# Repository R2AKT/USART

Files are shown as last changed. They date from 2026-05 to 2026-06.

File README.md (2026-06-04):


License addendum - https://github.com/R2AKT/USART/blob/main/Addendum.txt
# USART
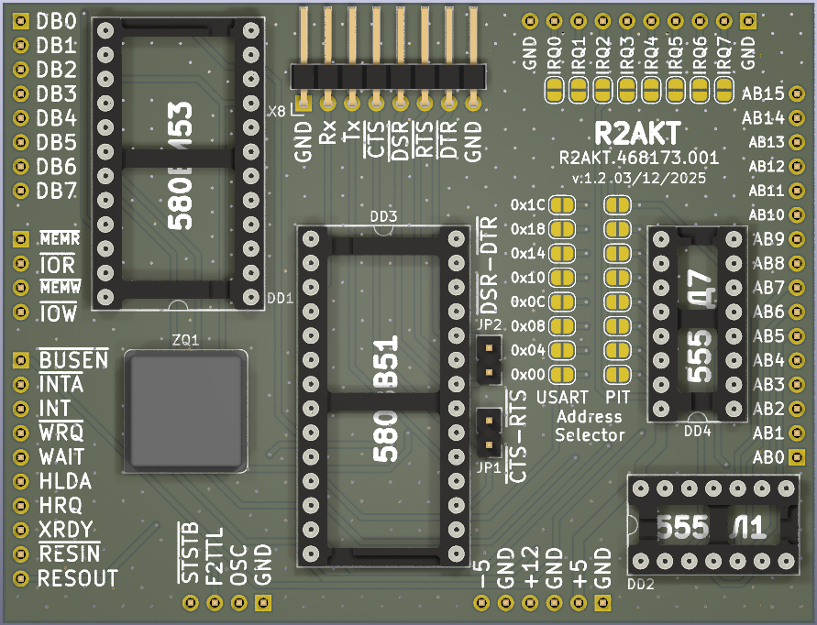
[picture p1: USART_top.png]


Serial port module (USART). For Mega-80 (Mega-580) DIY 8-bit micro-computer - https://github.com/R2AKT/Mega-80.

Based on 580VV51 (8251) and 580VI53 (8253).

Status: Tested. Prescaler x1 and x16, speed up to 38400.

Модуль последовательного порта (USART). Для самодельной 8-битной микро-ЭВМ - https://github.com/R2AKT/Mega-80.

На основе 580ВВ51 (8251) и 580ВИ53 (8253).

Статус: Протестирован. Работает в режиме x1 и x16, на скорости до 38400.

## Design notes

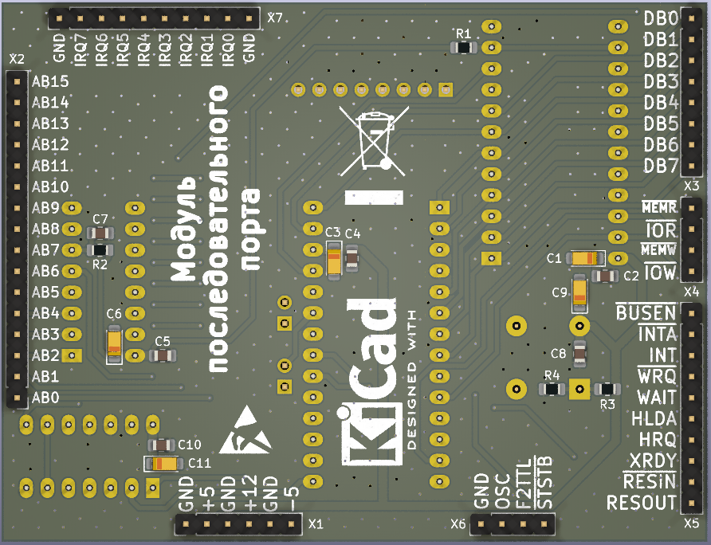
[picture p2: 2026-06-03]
USART_btn.png

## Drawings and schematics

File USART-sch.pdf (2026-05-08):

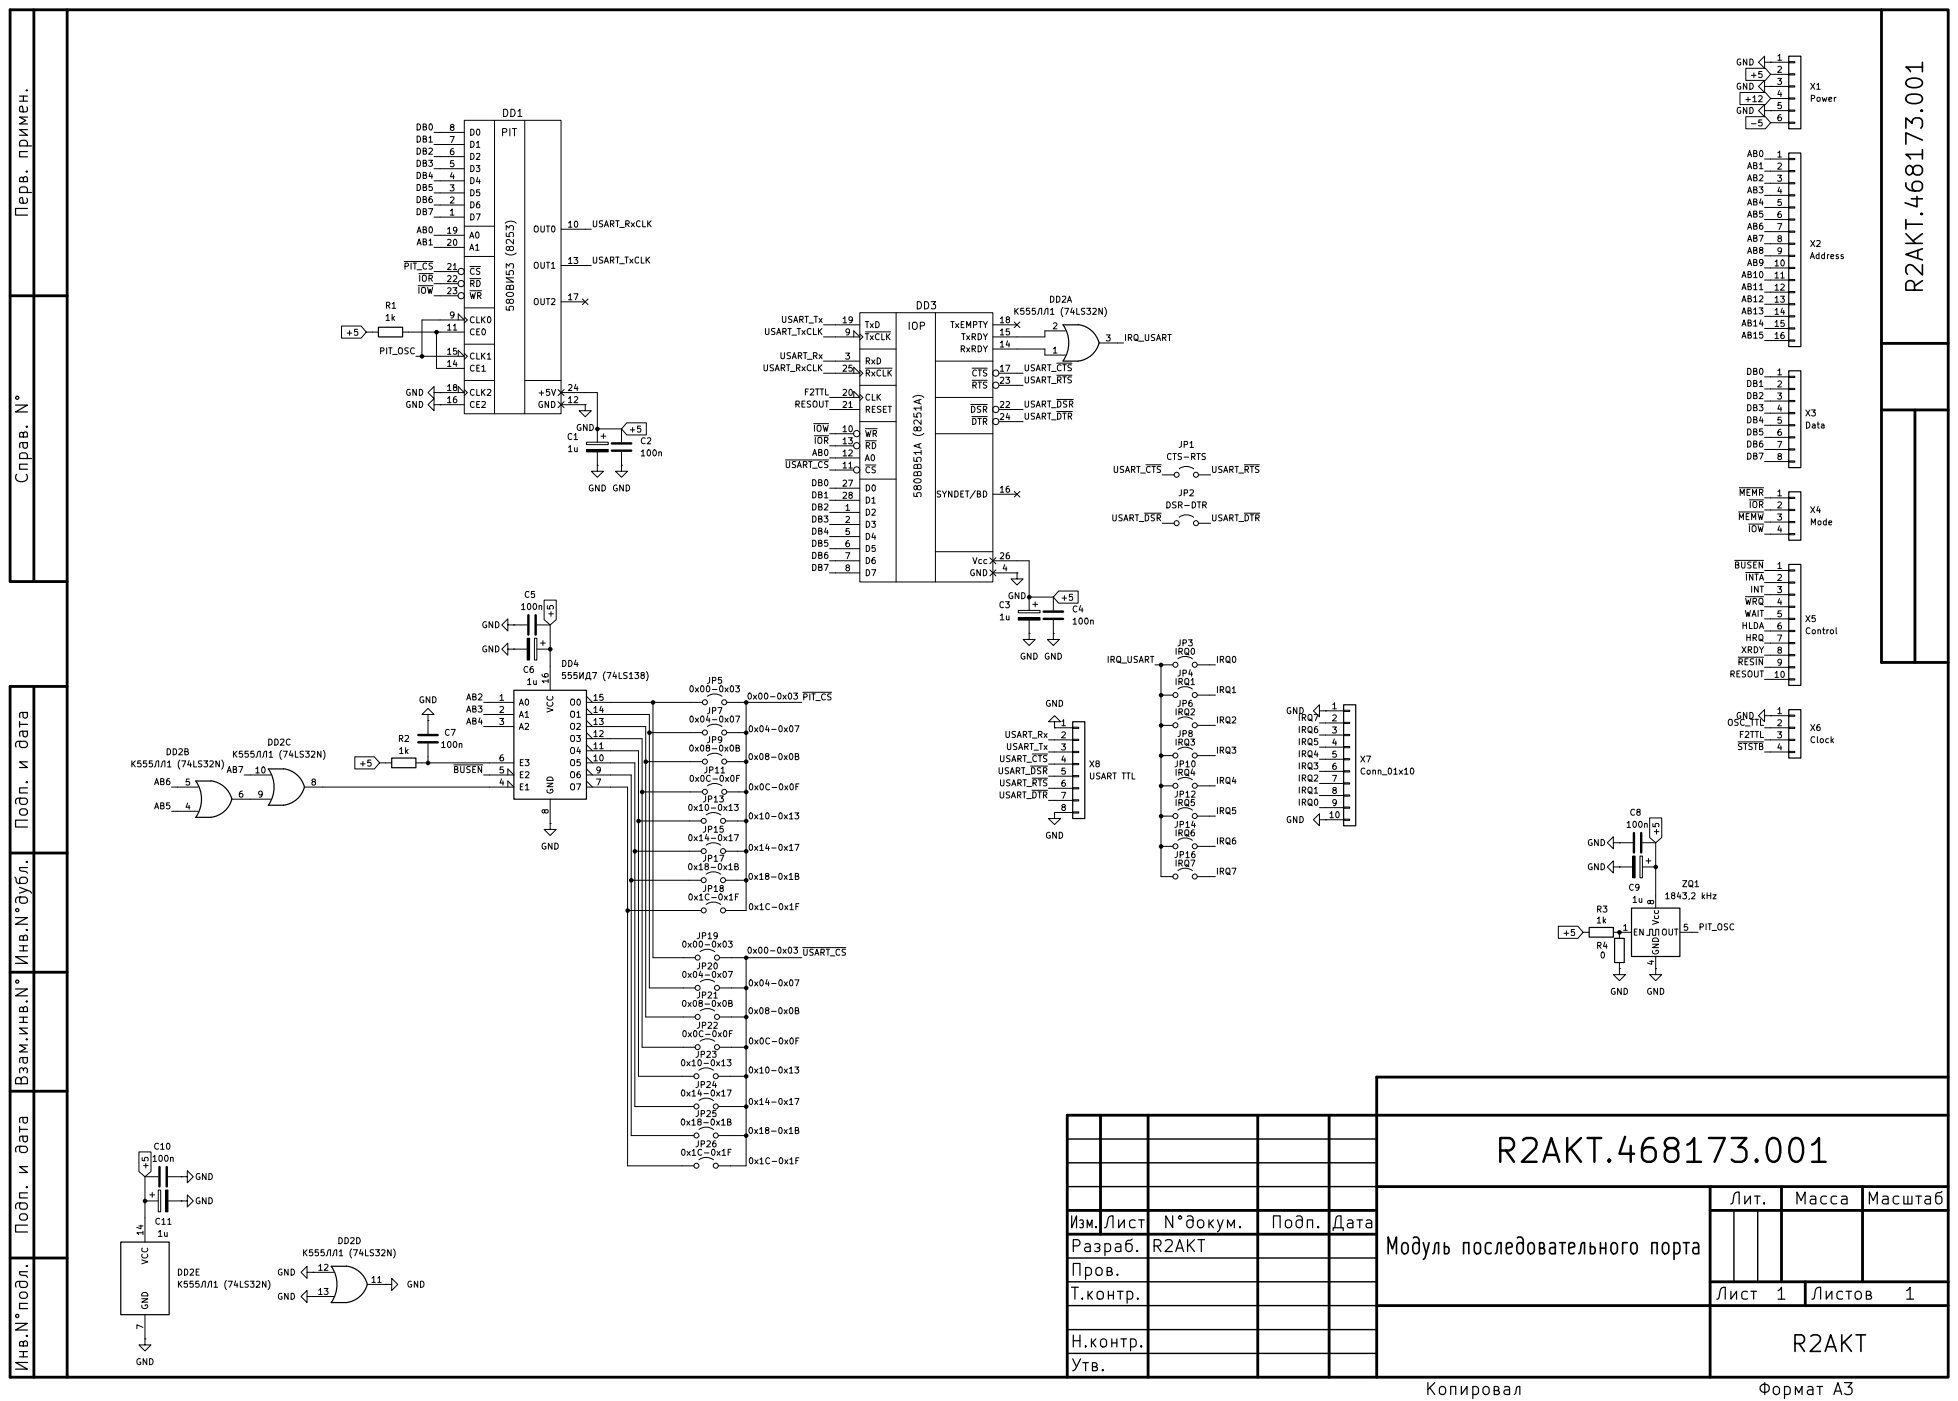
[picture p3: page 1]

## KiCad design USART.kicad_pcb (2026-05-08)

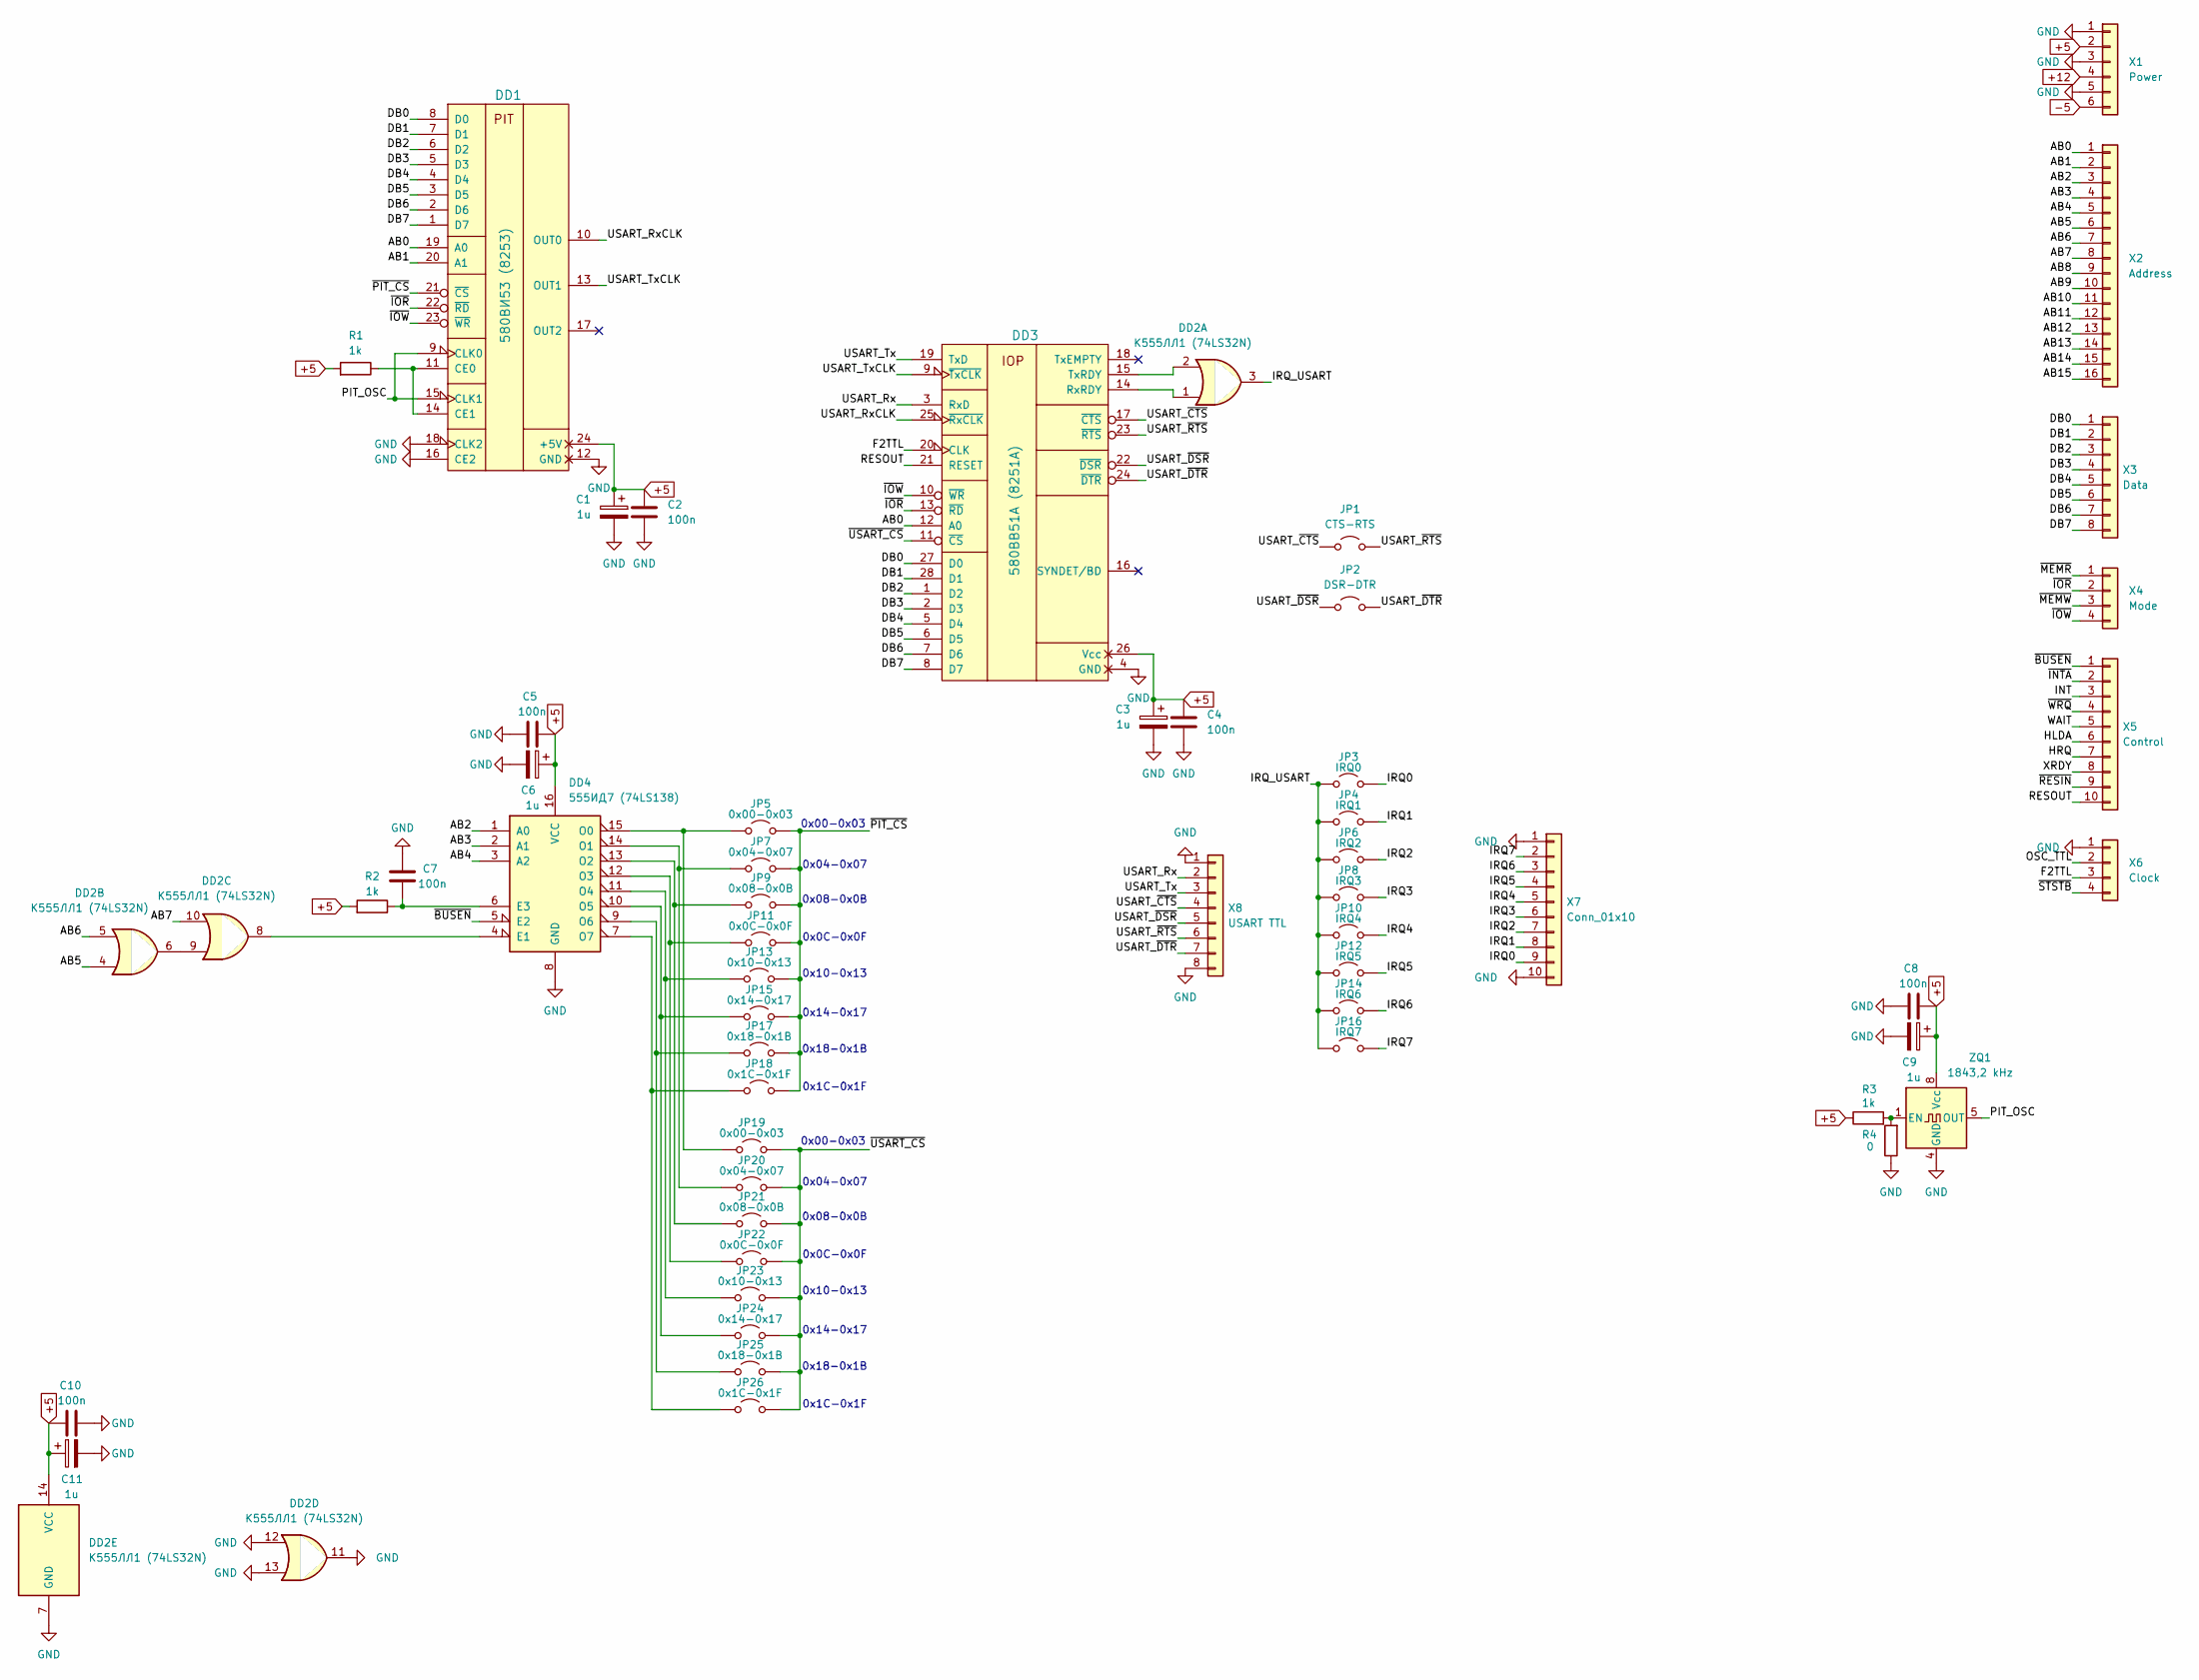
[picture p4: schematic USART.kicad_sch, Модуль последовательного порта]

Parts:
C1, C3, C6, C9, C11: 1u; CP_EIA-3216-18_Kemet-A_Pad1.58x1.35mm_HandSolder
C2, C4, C5, C7, C8, C10: 100n; C_0805_2012Metric_Pad1.18x1.45mm_HandSolder
DD1: 580ВИ53 (8253); DIP-24_W15.24mm_Socket_LongPads
DD2: К555ЛЛ1 (74LS32N); DIP-14_W7.62mm_Socket_LongPads
DD3: 580ВВ51А (8251A); DIP-28_W15.24mm_Socket_LongPads
DD4: 555ИД7 (74LS138); DIP-16_W7.62mm_Socket_LongPads
JP1: CTS-RTS; PinHeader_1x02_P2.54mm_Vertical
JP2: DSR-DTR; PinHeader_1x02_P2.54mm_Vertical
JP3: IRQ0; SolderJumper-2_P1.3mm_Open_RoundedPad1.0x1.5mm
JP4: IRQ1; SolderJumper-2_P1.3mm_Open_RoundedPad1.0x1.5mm
JP5, JP19: 0x00-0x03; SolderJumper-2_P1.3mm_Open_RoundedPad1.0x1.5mm
JP6: IRQ2; SolderJumper-2_P1.3mm_Open_RoundedPad1.0x1.5mm
JP7, JP20: 0x04-0x07; SolderJumper-2_P1.3mm_Open_RoundedPad1.0x1.5mm
JP8: IRQ3; SolderJumper-2_P1.3mm_Open_RoundedPad1.0x1.5mm
JP9, JP21: 0x08-0x0B; SolderJumper-2_P1.3mm_Open_RoundedPad1.0x1.5mm
JP10: IRQ4; SolderJumper-2_P1.3mm_Open_RoundedPad1.0x1.5mm
JP11, JP22: 0x0C-0x0F; SolderJumper-2_P1.3mm_Open_RoundedPad1.0x1.5mm
JP12: IRQ5; SolderJumper-2_P1.3mm_Open_RoundedPad1.0x1.5mm
JP13, JP23: 0x10-0x13; SolderJumper-2_P1.3mm_Open_RoundedPad1.0x1.5mm
JP14: IRQ6; SolderJumper-2_P1.3mm_Open_RoundedPad1.0x1.5mm
JP15, JP24: 0x14-0x17; SolderJumper-2_P1.3mm_Open_RoundedPad1.0x1.5mm
JP16: IRQ7; SolderJumper-2_P1.3mm_Open_RoundedPad1.0x1.5mm
JP17, JP25: 0x18-0x1B; SolderJumper-2_P1.3mm_Open_RoundedPad1.0x1.5mm
JP18, JP26: 0x1C-0x1F; SolderJumper-2_P1.3mm_Open_RoundedPad1.0x1.5mm
R1, R2, R3: 1k; R_0805_2012Metric_Pad1.20x1.40mm_HandSolder
R4: 0; R_0805_2012Metric_Pad1.20x1.40mm_HandSolder
X1: Power; PinHeader_1x06_P2.54mm_Vertical
X2: Address; PinHeader_1x16_P2.54mm_Vertical
X3: Data; PinHeader_1x08_P2.54mm_Vertical
X4: Mode; PinHeader_1x04_P2.54mm_Vertical
X5: Control; PinHeader_1x10_P2.54mm_Vertical
X6: Clock; PinHeader_1x04_P2.54mm_Vertical
X7: Conn_01x10; PinHeader_1x10_P2.54mm_Vertical
X8: USART TTL; PinHeader_1x08_P2.54mm_Horizontal
ZQ1: 1843,2 kHz; Oscillator_DIP-8_LargePads

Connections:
+5: C1.1, C2.1, C3.1, C4.1, C5.1, C6.1, C8.1, C9.1, C10.1, C11.1, DD1.24 (+5V), DD2.14 (VCC), DD3.26 (Vcc), DD4.16 (VCC), R1.2, R2.2, R3.1, X1.2, ZQ1.8 (Vcc)
+12: X1.4
-5: X1.6
/AB0: DD1.19 (A0), DD3.12 (A0), X2.1
/AB1: DD1.20 (A1), X2.2
/AB2: DD4.1 (A0), X2.3
/AB3: DD4.2 (A1), X2.4
/AB4: DD4.3 (A2), X2.5
/AB5: DD2.4, X2.6
/AB6: DD2.5, X2.7
/AB7: DD2.10, X2.8
/AB8: X2.9
/AB9: X2.10
/AB10: X2.11
/AB11: X2.12
/AB12: X2.13
/AB13: X2.14
/AB14: X2.15
/AB15: X2.16
/DB0: DD1.8 (D0), DD3.27 (D0), X3.1
/DB1: DD1.7 (D1), DD3.28 (D1), X3.2
/DB2: DD1.6 (D2), DD3.1 (D2), X3.3
/DB3: DD1.5 (D3), DD3.2 (D3), X3.4
/DB4: DD1.4 (D4), DD3.5 (D4), X3.5
/DB5: DD1.3 (D5), DD3.6 (D5), X3.6
/DB6: DD1.2 (D6), DD3.7 (D6), X3.7
/DB7: DD1.1 (D7), DD3.8 (D7), X3.8
/F2TTL: DD3.20 (CLK), X6.3
/HLDA: X5.6
/HRQ: X5.7
/INT: X5.3
/IRQ0: JP3.2 (B), X7.9
/IRQ1: JP4.2 (B), X7.8
/IRQ2: JP6.2 (B), X7.7
/IRQ3: JP8.2 (B), X7.6
/IRQ4: JP10.2 (B), X7.5
/IRQ5: JP12.2 (B), X7.4
/IRQ6: JP14.2 (B), X7.3
/IRQ7: JP16.2 (B), X7.2
/IRQ_USART: DD2.3, JP3.1 (A), JP4.1 (A), JP6.1 (A), JP8.1 (A), JP10.1 (A), JP12.1 (A), JP14.1 (A), JP16.1 (A)
/OSC_TTL: X6.2
/PIT_OSC: DD1.9 (CLK0), DD1.15 (CLK1), ZQ1.5 (OUT)
/RESOUT: DD3.21 (RESET), X5.10
/USART_Rx: DD3.3 (RxD), X8.2
/USART_RxCLK: DD1.10 (OUT0), DD3.25 (~RxCLK)
/USART_Tx: DD3.19 (TxD), X8.3
/USART_TxCLK: DD1.13 (OUT1), DD3.9 (~TxCLK)
/USART_~CTS: DD3.17 (~CTS), JP1.1 (A), X8.4
/USART_~DSR: DD3.22 (~DSR), JP2.1 (A), X8.5
/USART_~DTR: DD3.24 (~DTR), JP2.2 (B), X8.7
/USART_~RTS: DD3.23 (~RTS), JP1.2 (B), X8.6
/WAIT: X5.5
/XRDY: X5.8
/~BUSEN: DD4.5 (E2), X5.1
/~INTA: X5.2
/~IOR: DD1.22 (~RD), DD3.13 (~RD), X4.2
/~IOW: DD1.23 (~WR), DD3.10 (~WR), X4.4
/~MEMR: X4.1
/~MEMW: X4.3
/~PIT_CS: DD1.21 (~CS), JP5.2 (B), JP7.2 (B), JP9.2 (B), JP11.2 (B), JP13.2 (B), JP15.2 (B), JP17.2 (B), JP18.2 (B)
/~RESIN: X5.9
/~STSTB: X6.4
/~USART_CS: DD3.11 (~CS), JP19.2 (B), JP20.2 (B), JP21.2 (B), JP22.2 (B), JP23.2 (B), JP24.2 (B), JP25.2 (B), JP26.2 (B)
/~WRQ: X5.4
GND: C1.2, C2.2, C3.2, C4.2, C5.2, C6.2, C7.2, C8.2, C9.2, C10.2, C11.2, DD1.12 (GND), DD1.16 (CE2), DD1.18 (CLK2), DD2.7 (GND), DD2.11, DD2.12, DD2.13, DD3.4 (GND), DD4.8 (GND), R4.1, X1.1, X1.3, X1.5, X6.1, X7.1, X7.10, X8.1, X8.8, ZQ1.4 (GND)
unnamed: DD1.11 (CE0), DD1.14 (CE1), R1.1
unnamed: DD2.6, DD2.9
unnamed: DD2.1, DD3.14 (RxRDY)
unnamed: DD2.2, DD3.15 (TxRDY)
unnamed: DD2.8, DD4.4 (E1)
unnamed: C7.1, DD4.6 (E3), R2.1
unnamed: DD4.15 (O0), JP5.1 (A), JP19.1 (A)
unnamed: DD4.14 (O1), JP7.1 (A), JP20.1 (A)
unnamed: DD4.13 (O2), JP9.1 (A), JP21.1 (A)
unnamed: DD4.12 (O3), JP11.1 (A), JP22.1 (A)
unnamed: DD4.11 (O4), JP13.1 (A), JP23.1 (A)
unnamed: DD4.10 (O5), JP15.1 (A), JP24.1 (A)
unnamed: DD4.9 (O6), JP17.1 (A), JP25.1 (A)
unnamed: DD4.7 (O7), JP18.1 (A), JP26.1 (A)
unnamed: R3.2, R4.2, ZQ1.1 (EN)

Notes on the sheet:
0x00-0x03
0x1C-0x1F
0x18-0x1B
0x08-0x0B
0x14-0x17
0x10-0x13
0x04-0x07
0x0C-0x0F

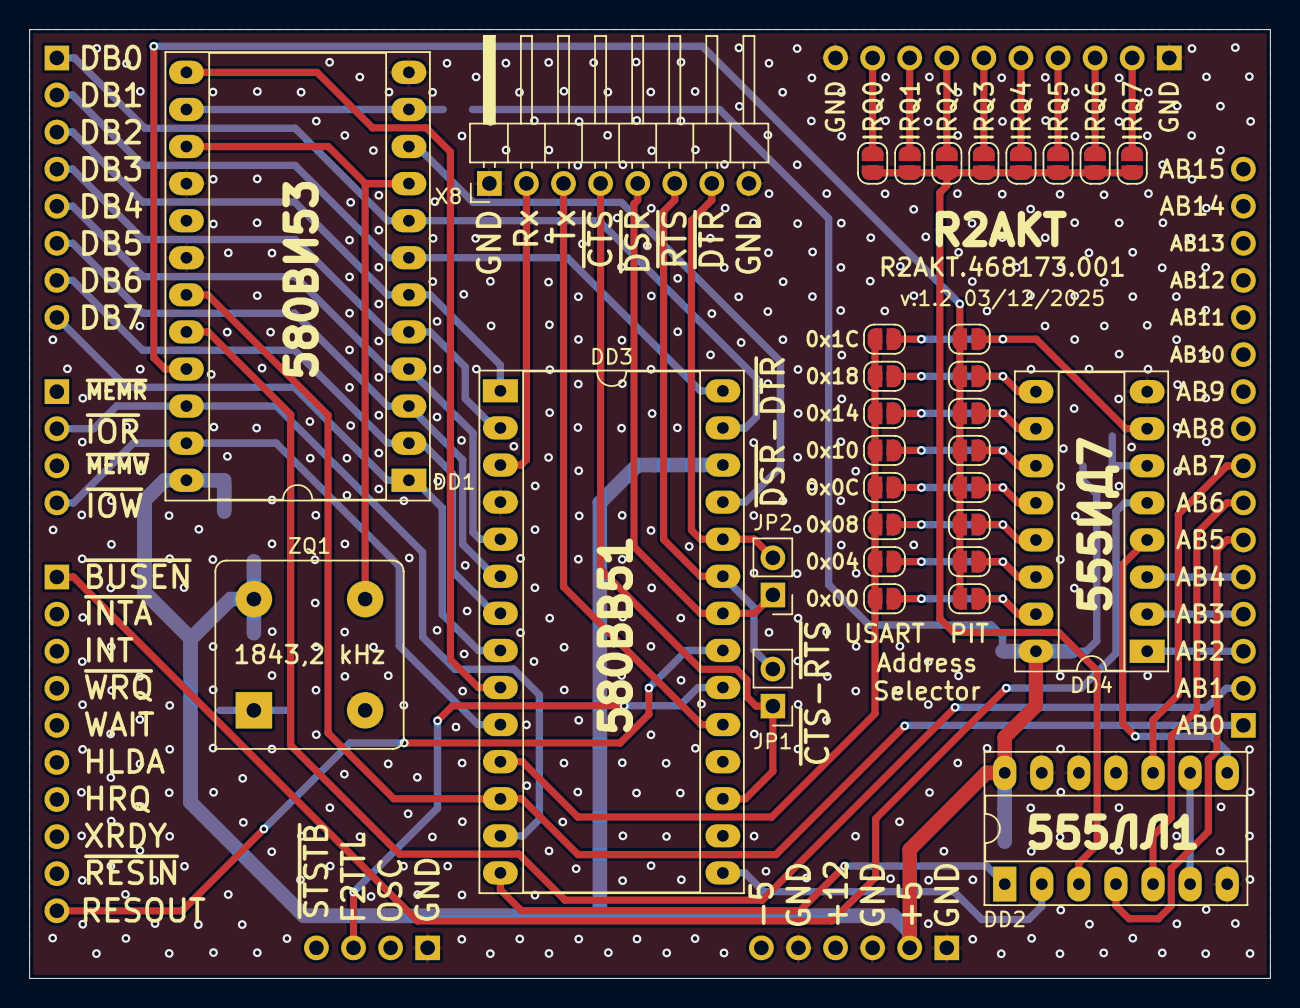
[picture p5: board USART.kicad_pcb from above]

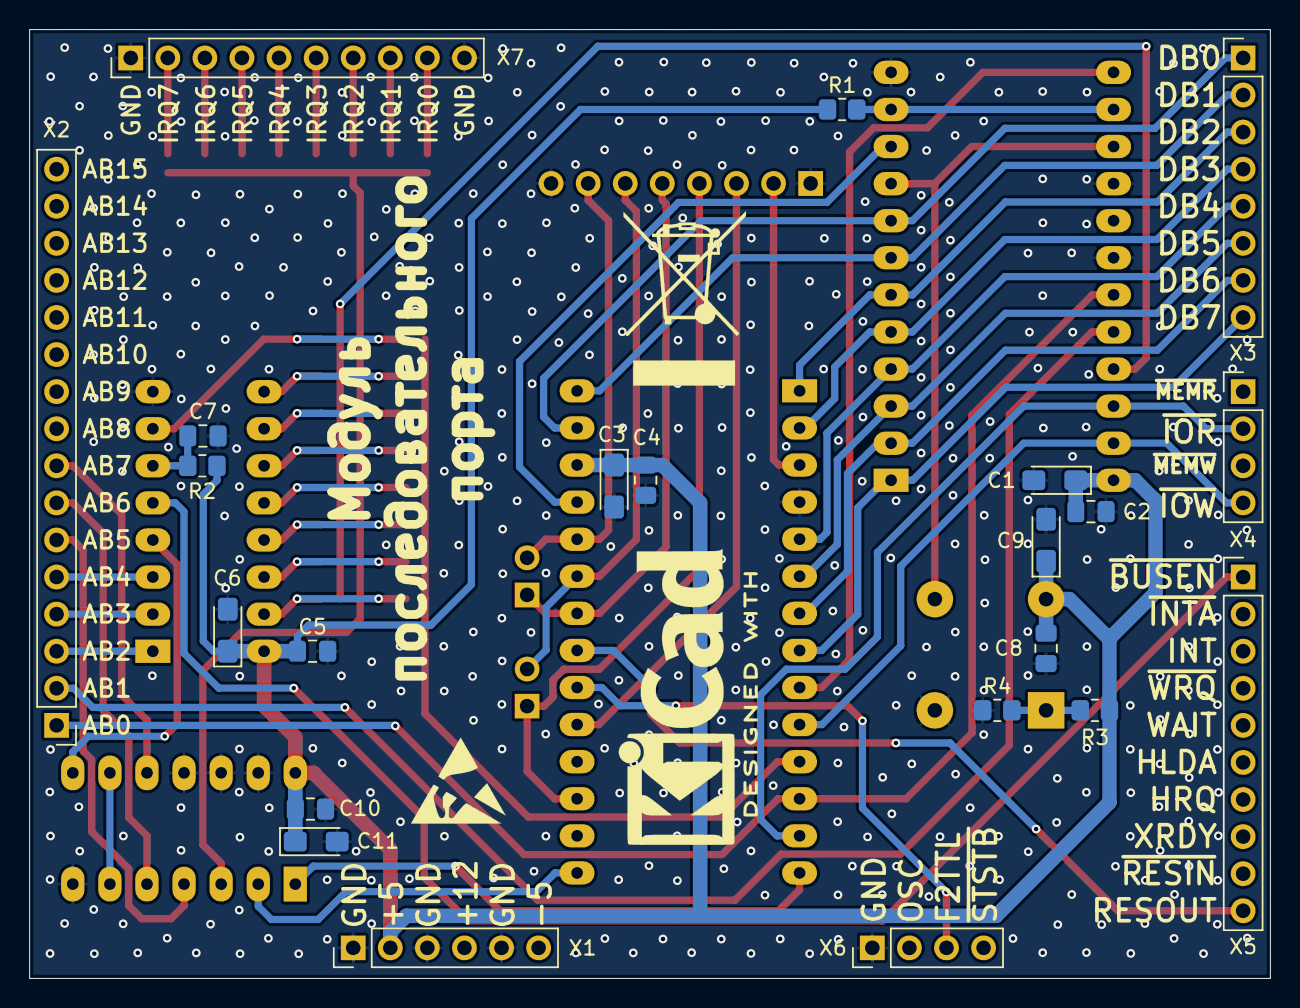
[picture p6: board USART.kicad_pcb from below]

Board: 2 copper layers, 85.0 x 65.0 mm, 54 parts (22 on the bottom side), 58 nets.

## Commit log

2025-12-03 Update+fix
    - Replaced the standard logic oscillator with a monolithic quartz oscillator;
    - Fixed the 'CLK' source of the 580VV51 (8251);
    - Connected the reset signal of the 580VV51 (8251).
    - Заменен генератор на стандартной логике на монолитный кварцевый генератор;
    - Исправлен источник 'CLK' у 580ВВ51 (8251);
    - Подключен сигнал сброса у 580ВВ51 (8251).
    [USART.kicad_pcb, USART.kicad_sch]
2025-12-04 Add files via upload
    Added a table of speed generator frequencies and divider values for different exchange rates.
    Добавлена таблица частот генератора скорости и значения делителя для различных скоростей обмена.
2026-01-20 Add files via upload
    Changed IRQ bus pin's
    Изменены пины шины IRQ
    [USART.kicad_pcb, USART.kicad_sch]
2026-03-08 Add files via upload
    Software implementation. Base function's.
    Программная реализация. Базовые функции.

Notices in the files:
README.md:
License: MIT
